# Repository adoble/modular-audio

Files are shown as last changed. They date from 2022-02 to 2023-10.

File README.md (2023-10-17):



# Modular Audio Project - Amplifier Module

An class D amplifier module that can select other digital sources (I2S, S/PDIF).

## System Diagram

### Functional Components

<!-- Removed the ELK renderer as causing problems - see https://github.com/mermaid-js/mermaid-cli/issues/594 -->
<!-- Old code was (first line of the mermaid description): -->
<!-- %%{init: {"flowchart": {"defaultRenderer": "elk"}} }%% -->

```mermaid
flowchart LR

main_ctrl["Main Controller"] -- Parallel Bus --- i2sm[I2S-Multiplexer];
wifi --- antenna1((Antenna <br> 1));

main_ctrl -- I2C --- dsp;
main_ctrl -- SPI+2 --- wifi["WiFi Co-Processor"]
i2sm -- I2S --- dsp["Digital Signal <br> Processor"] -- I2S --- amp[Amplifier];
dsp -- I2S --- toslink_out_converter[TOSLINK<br>Converter] -- "S/PDIF" --- toslink_out{{TOSLINK <br> Out}};

style dsp stroke-dasharray: 5 5;
style toslink_out_converter stroke-dasharray: 5 5;
style toslink_out stroke-dasharray: 5 5;

subgraph sources [Sources-In]
    cd{{CD}};
    dvd{{DVD}};
    tos_link_in{{Toslink In}}
end

subgraph source_sel_display [Source Selection Lights]
    direction LR
    cd_source_selected((CD ))
    dvd_source_selected((DVD))
    bluetooth_source_selected((BT ))
    wlan_source_selected((WLAN))
    dab_source_selected((DAB))
end

antenna2((Antenna <br> 2)) --- airlink;
airlink["Airlink/Bluetooth"] -- I2S --- i2sm
cd -- I2S  --- i2sm;
dvd -- "S/PDIF" --- spdif["S/PDIF Module"] -- I2S --- i2sm;
internet-radio["Internet Radio"] -- I2S --- i2sm

tos_link_in -- "S/PDIF" --- toslink_converter[TOSLINK<br>Converter] -- I2S --- i2sm; 
dab["DAB Radio"] -- I2S --- i2sm

amp --- left{{Left}} --- left_spk((Left <br> Speaker)) 
amp --- right{{Right}} --- right_spk((Right <br> Speaker)) 

dsp -- I2S --- sw-dac[Sub-Woofer DAC] --- sw-line-out{{Sub-Woofer<br>Line-Out}} --- active-sw((Active<br>Sub-Woofer))

vol_proc[Volume <br> Processor];
sel_source[Select <br> Source <br>];

subgraph controls[Controls]
    direction TB
    sel_source_btn((Select <br> Source Button))
    vol_knob((Volume <br> Knob))
end

sel_source --- source_sel_display
vol_knob --- vol_proc -- I2C+1--- main_ctrl;
sel_source_btn --- sel_source -- I2C+1--- main_ctrl;

%%click main_ctrl "https://github.com/adoble/modular-audio/blob/main/README.md#controller"%%
%%click i2sm "https://github.com/adoble/modular-audio/tree/main/hardware/i2s-multiplexer" "Click to see sub-repository"%%
```

### Power

```mermaid
    graph LR;

    net{{240V AV}};
    net ---- Relay;
    Relay --- smps[Switched Mode <br> Power Supply];
    smps ---- pwr_24v{24V};
    smps --- reg_5v[5V Regulator];
    smps --- reg_3v3[3.3V Regulator];
    reg_5v --- pwr_5v{5V};
    reg_3v3 --- pwr_3v3{3.3V};

    Battery --- pwr_on_off(("Power <br> On/Off <br> Switch")) --- Relay; 
```

### Symbols used in the Diagrams

```mermaid
graph LR;

subgraph key[Key]
    transducer((<small>Transducer<small>)) ---  pwr_net{<small>Power<br>Net<small>} --- module[<small>Hardware Module<small>] --- ext{{<small>External<br>Connection<small>}};
end
style key stroke-dasharray: 5 5, fill-opacity: 0;

%% Render links invisible
linkStyle 0 stroke:none
linkStyle 1 stroke:none
linkStyle 2 stroke:none
```

<!-- ![System Diagram](./docs/img/Modular-Amplifier.png) -->

## Functional Component Descriptions

### Controller

Work in Progress!

The controller has the following tasks:

* Select sources
* Receive input fron the volume control and adjust the volume over the DSP. 
* Receive input from the button banks. These are used to interact with the display. 
* Interface with an (Airlift) Wifi board over an extended SPI interface. This is used to download station lists and also 
to control the internet radio module.

Software is [here](/software/main-controller).

Hardware is [here](/hardware/controller).

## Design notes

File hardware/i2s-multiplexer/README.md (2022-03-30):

# I2S Multiplexer

This module routes I2S signals up to 6 sources to the amplifier module  - see the [module overview](../../README.md).

The design principles are:

* Each I2S signal (BCLK, LRCLK, DATA, MCLK) belonging to source are routed through the same buffers so has to minimise differences in buffer propagation delays and with it, differences in the relative timing of the signals with one another. 
* Each I2S signal belonging to a source have the the same track length - gain to moinimisd differences in the relative timing of the signals with one another. 

## Control Signals 

| Signal | Description |
| --- | --- |
| A0, A1, A2 | Address of the source required. Only addresses from 0x0 to 0x5 are allowed. If another address is given the behaviour is not defined. |
| SRC_EN | This should be set LOW before changing  A0..2 and HIGH again once they have been set. | 

## Power

The board requires 3.3 Volt.

## Schematic

Schematic done with [KiCad 6](https://www.kicad.org/) and all files are in this format. An image of the schmematic is:

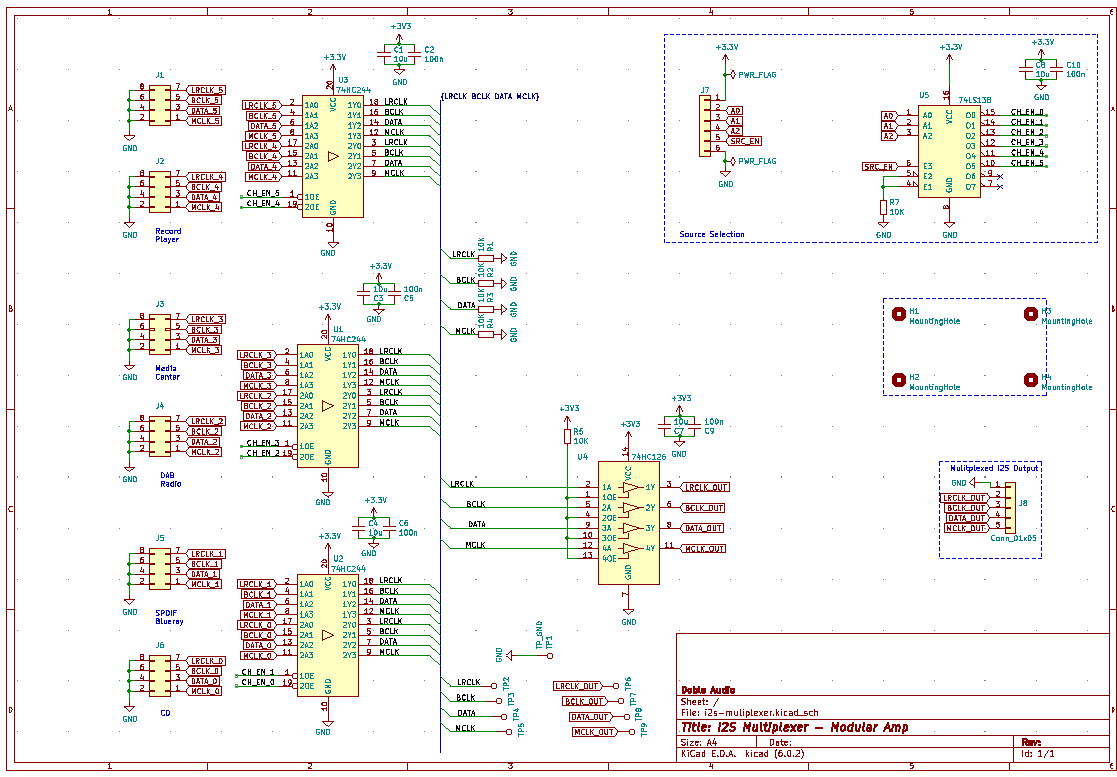
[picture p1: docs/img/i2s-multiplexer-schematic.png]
Schematic


## PCB Layout 

PCB layout is done with [KiCad 6](https://www.kicad.org/)and all files are in this format. An image of the PCB layout is:

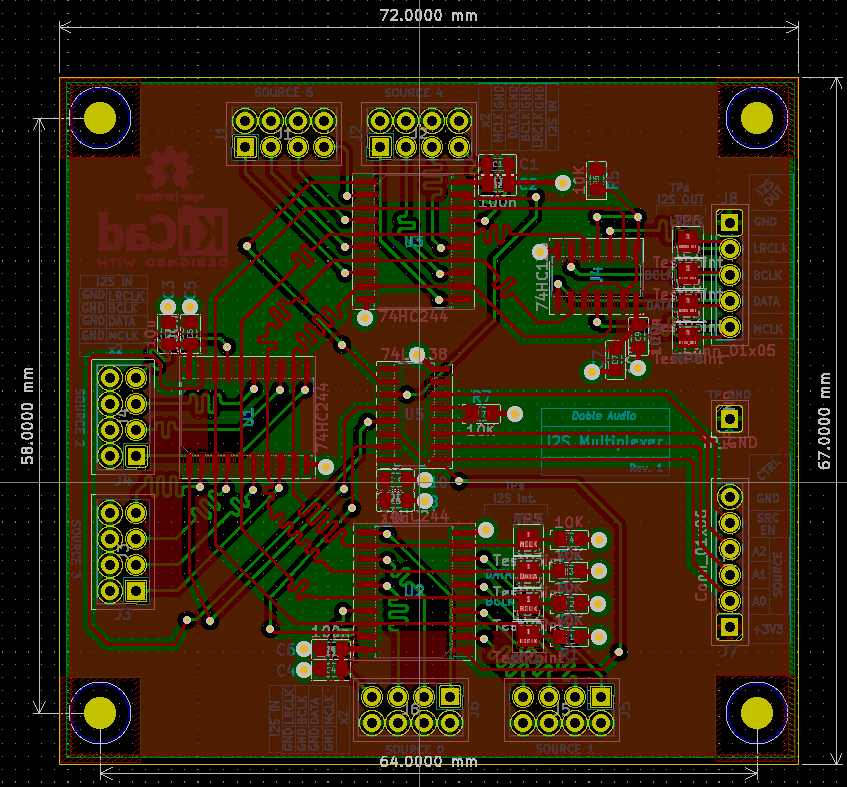
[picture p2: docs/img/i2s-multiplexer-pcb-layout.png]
PCB Layout


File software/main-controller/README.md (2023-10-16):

This is the main controller software for the modular amplifier.

It uses the [Embassy](https://embassy.dev/) framework for running asynchronous tasks. 

# Project Structure

TODO

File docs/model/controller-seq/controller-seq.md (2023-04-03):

# Controller Sequence Diagram

```mermaid

sequenceDiagram

participant system
participant [task]init
participant [task]select_source
participant [struct]SelectSourceDriver
participant [struct]Source
participant [struct]I2SMultiplexerDriver

system--) [task]init : start
activate [task]init
[task]init->>+SelectSourceDriver: new
SelectSourceDriver->>-[task]init: select_source_driver
deactivate [task]init

system--)[task]select_source :  interrupt on source change
activate [task]select_source
[task]select_source->>+SelectSourceDriver : changed_source

SelectSourceDriver->>-[task]select_source : source
[task]select_source->>[struct]Source : activate

[struct]Source->>[struct]I2SMultiplexerDriver : set_source

deactivate [task]select_source

```

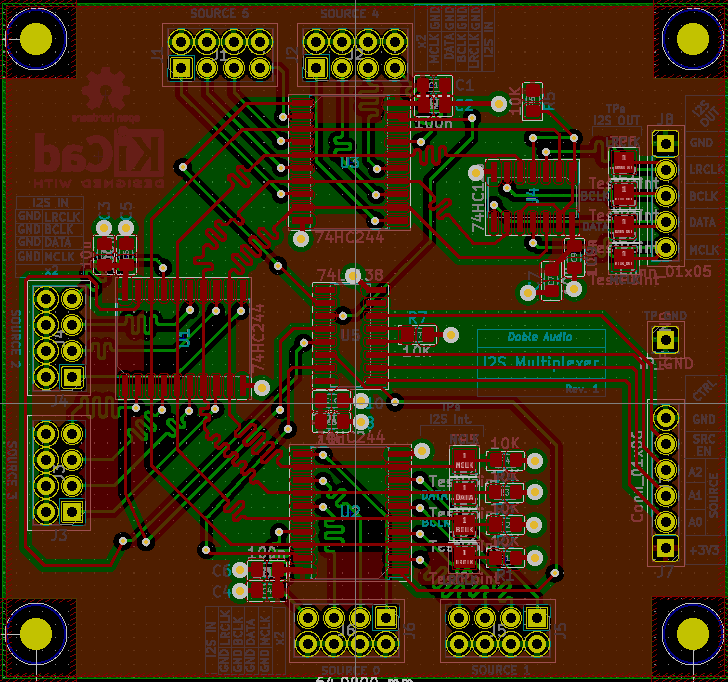
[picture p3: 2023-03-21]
docs/img/i2s-multiplexer-pcb-layout.bmp

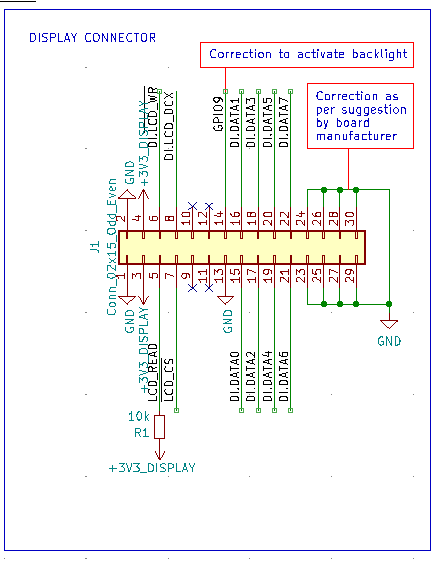
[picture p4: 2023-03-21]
docs/img/controller-display-connector.png

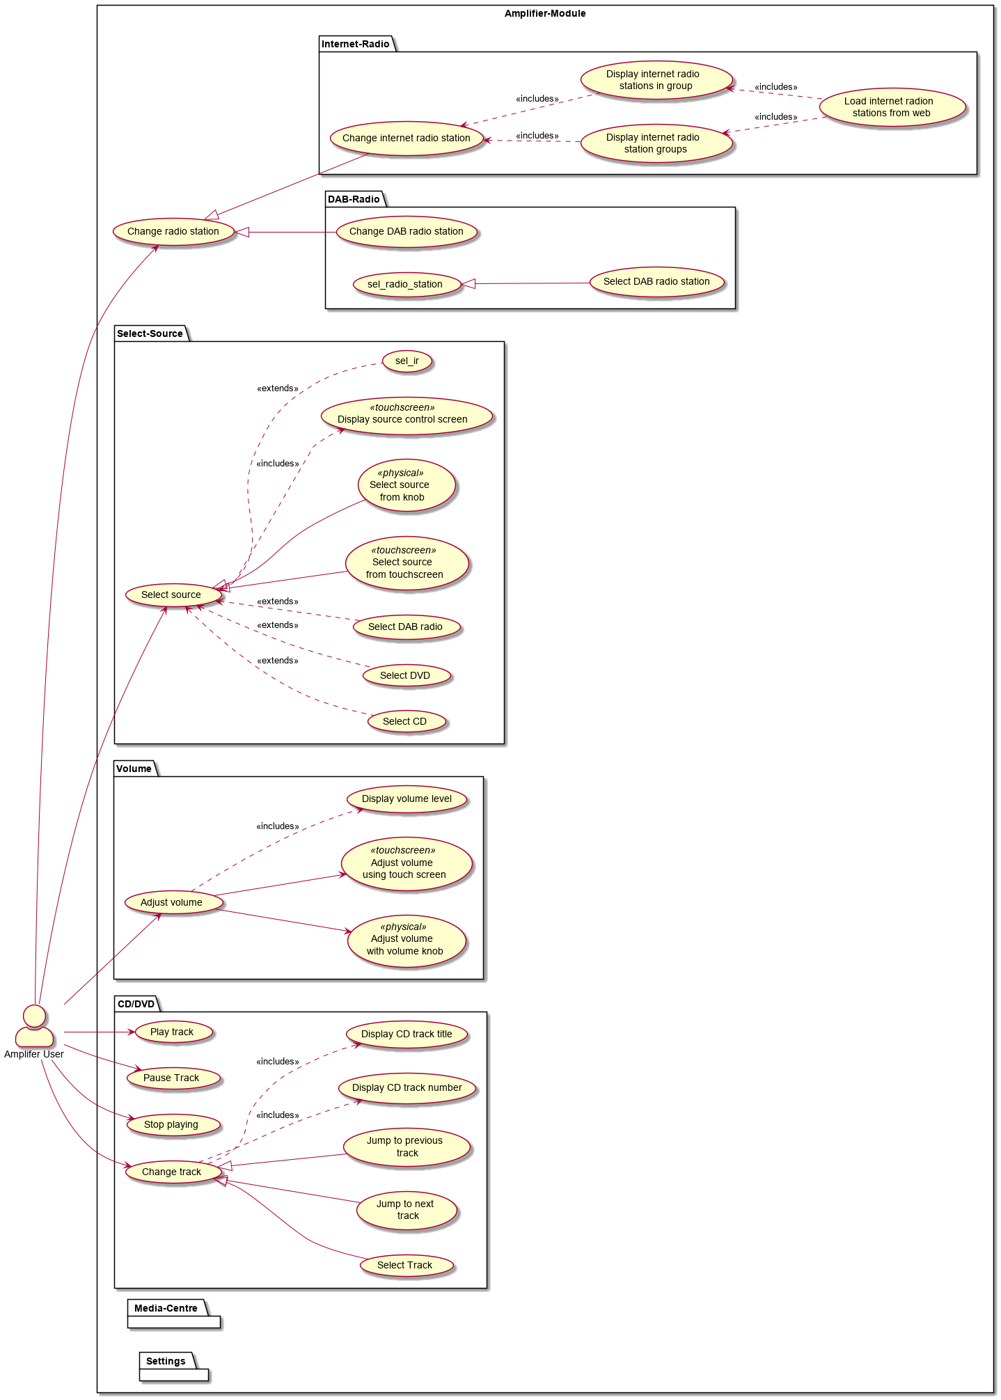
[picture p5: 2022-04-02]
out/docs/model/use-cases/use-cases/use-cases-page1.png

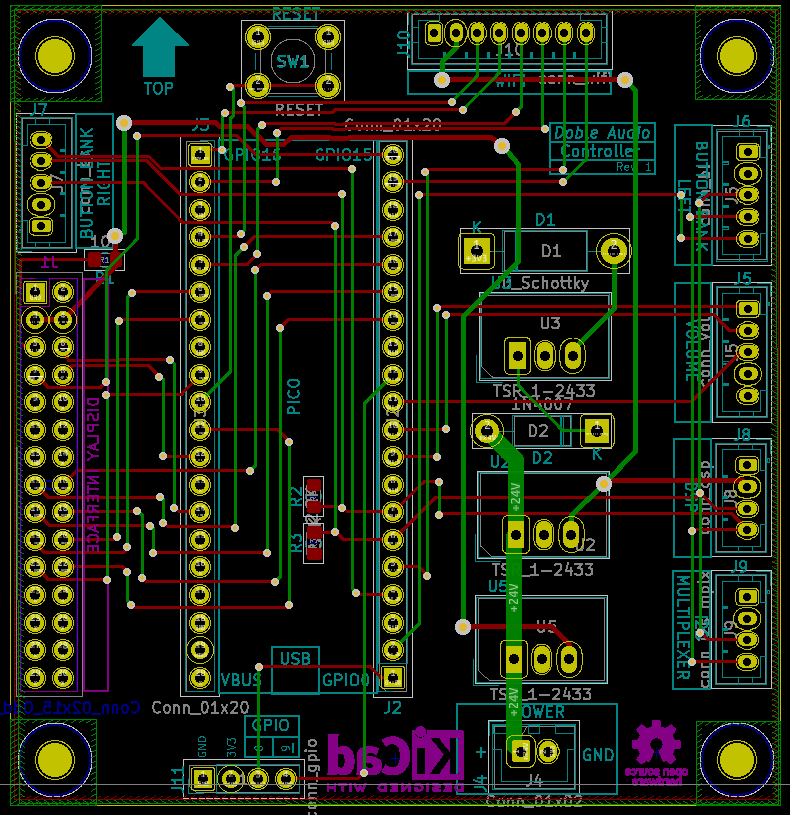
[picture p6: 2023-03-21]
docs/img/controller-pcb.png

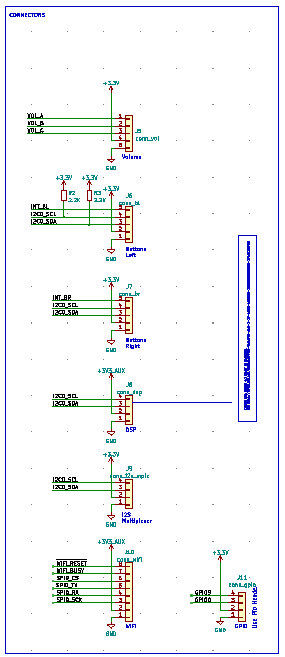
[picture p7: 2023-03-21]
docs/img/controller-connectors.png

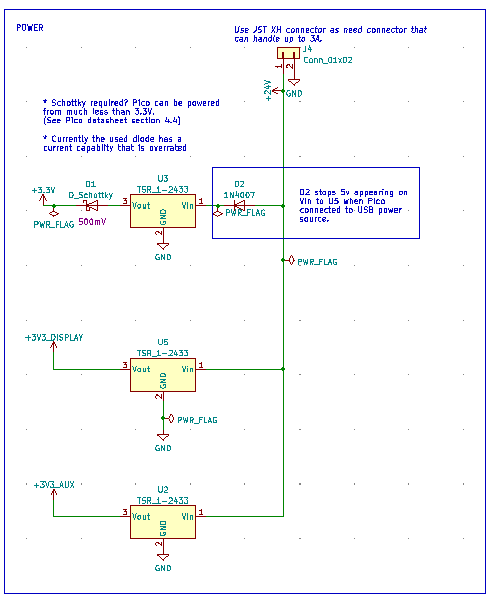
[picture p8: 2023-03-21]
docs/img/controller-power.png

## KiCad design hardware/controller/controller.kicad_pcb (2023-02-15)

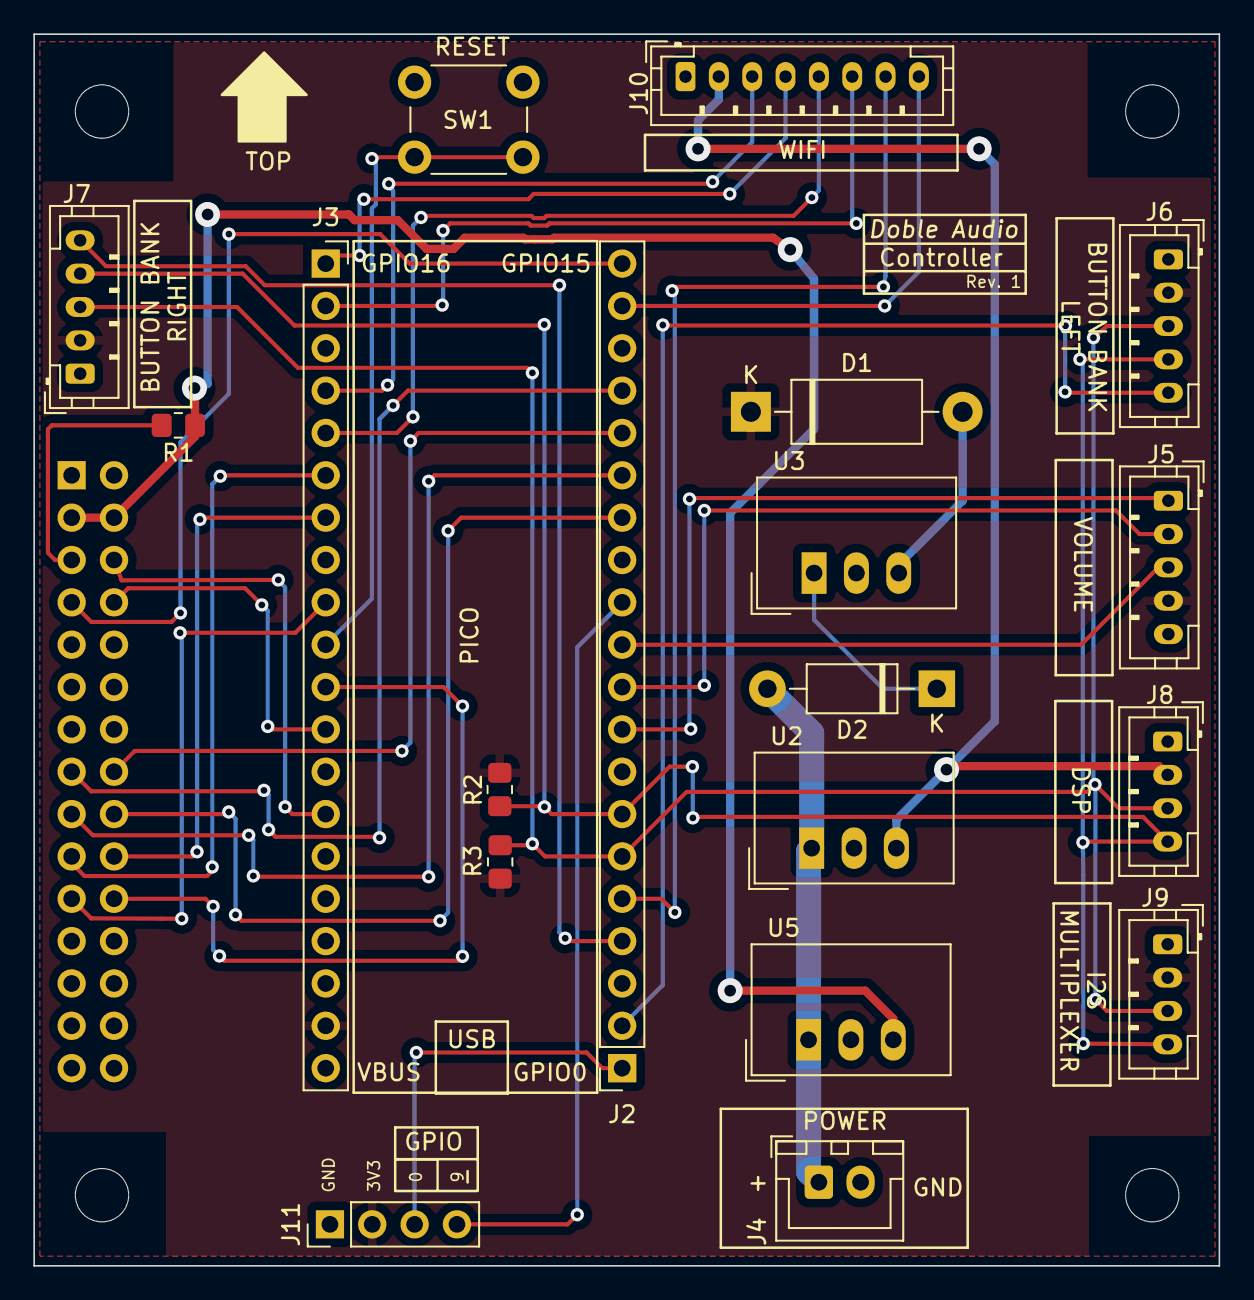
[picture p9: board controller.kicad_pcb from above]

Board: 2 copper layers, 71.1 x 73.9 mm, 24 parts (1 on the bottom side), 35 nets.

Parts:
D1: D_Schottky; D_DO-15_P12.70mm_Horizontal
D2: 1N4007; D_DO-41_SOD81_P10.16mm_Horizontal
H1, H2, H3, H4: MountingHole; MountingHole_3.2mm_M3
J1: Conn_02x15_Odd_Even; PinSocket_2x15_P2.54mm_Vertical
J2, J3: Conn_01x20; PinSocket_1x20_P2.54mm_Vertical
J4: Conn_01x02; JST_XH_B2B-XH-A_1x02_P2.50mm_Vertical
J5: conn_vol; JST_PH_B5B-PH-K_1x05_P2.00mm_Vertical
J6: conn_bl; JST_PH_B5B-PH-K_1x05_P2.00mm_Vertical
J7: conn_br; JST_PH_B5B-PH-K_1x05_P2.00mm_Vertical
J8: conn_dsp; JST_PH_B4B-PH-K_1x04_P2.00mm_Vertical
J9: conn_i2s_mplx; JST_PH_B4B-PH-K_1x04_P2.00mm_Vertical
J10: conn_wifi; JST_PH_B8B-PH-K_1x08_P2.00mm_Vertical
J11: conn_gpio; PinHeader_1x04_P2.54mm_Vertical
R1: 10k; R_0805_2012Metric_Pad1.20x1.40mm_HandSolder
R2, R3: 2.2K; R_0805_2012Metric_Pad1.20x1.40mm_HandSolder
SW1: RESET; SW_PUSH_6mm_H4.3mm
U2, U3, U5: TSR_1-2433; Converter_DCDC_TRACO_TSR-1_THT

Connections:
+3V3: D1.1 (K), J3.19, J5.4, J6.2, J7.2, J9.2, J11.2, R2.1, R3.1
+3V3_AUX: J8.2, J10.2, U2.3 (Vout)
+3V3_DISPLAY: J1.3, J1.4, R1.1, U5.3 (Vout)
+24V: D2.2 (A), J4.1, U2.1 (Vin), U5.1 (Vin)
/DI.DATA0: J1.15, J2.17
/DI.DATA1: J1.16, J2.16
/DI.DATA2: J1.17, J2.15
/DI.DATA3: J1.18, J2.14
/DI.DATA4: J1.19, J3.6
/DI.DATA5: J1.20, J3.7
/DI.DATA6: J1.21, J3.9
/DI.DATA7: J1.22, J3.11
/DI.LCD_DCX: J1.8, J3.12
/DI.~LCD_WR: J1.6, J3.14
/GPIO0: J2.1, J11.3
/GPIO9: J2.12, J11.4
/I2C0_SCL: J2.7, J6.4, J7.4, J8.4, J9.4, R2.2
/I2C0_SDA: J2.6, J6.3, J7.3, J8.3, J9.3, R3.2
/INT_BL: J2.2, J6.5
/INT_BR: J2.4, J7.5
/LCD_READ: J1.5, R1.2
/MCU_RESET: J3.10, SW1.2
/SPI0_CS: J3.2, J10.6
/SPI0_RX: J3.1, J10.4
/SPI0_SCK: J3.4, J10.3
/SPI0_TX: J3.5, J10.5
/VOL_A: J2.9, J5.1
/VOL_B: J2.10, J5.2
/VOL_C: J2.11, J5.3
/WIFI_BUSY: J2.5, J10.7
/~LCD_CS: J1.7, J2.20
/~WIFI_RESET: J2.19, J10.8
GND: J1.1, J1.2, J1.13, J2.3, J2.8, J2.13, J2.18, J3.3, J3.8, J3.18, J4.2, J5.5, J6.1, J7.1, J8.1, J9.1, J10.1, J11.1, SW1.1, U2.2 (GND), U3.2 (GND), U5.2 (GND)
unnamed: D1.2 (A), U3.3 (Vout)
unnamed: D2.1 (K), U3.1 (Vin)

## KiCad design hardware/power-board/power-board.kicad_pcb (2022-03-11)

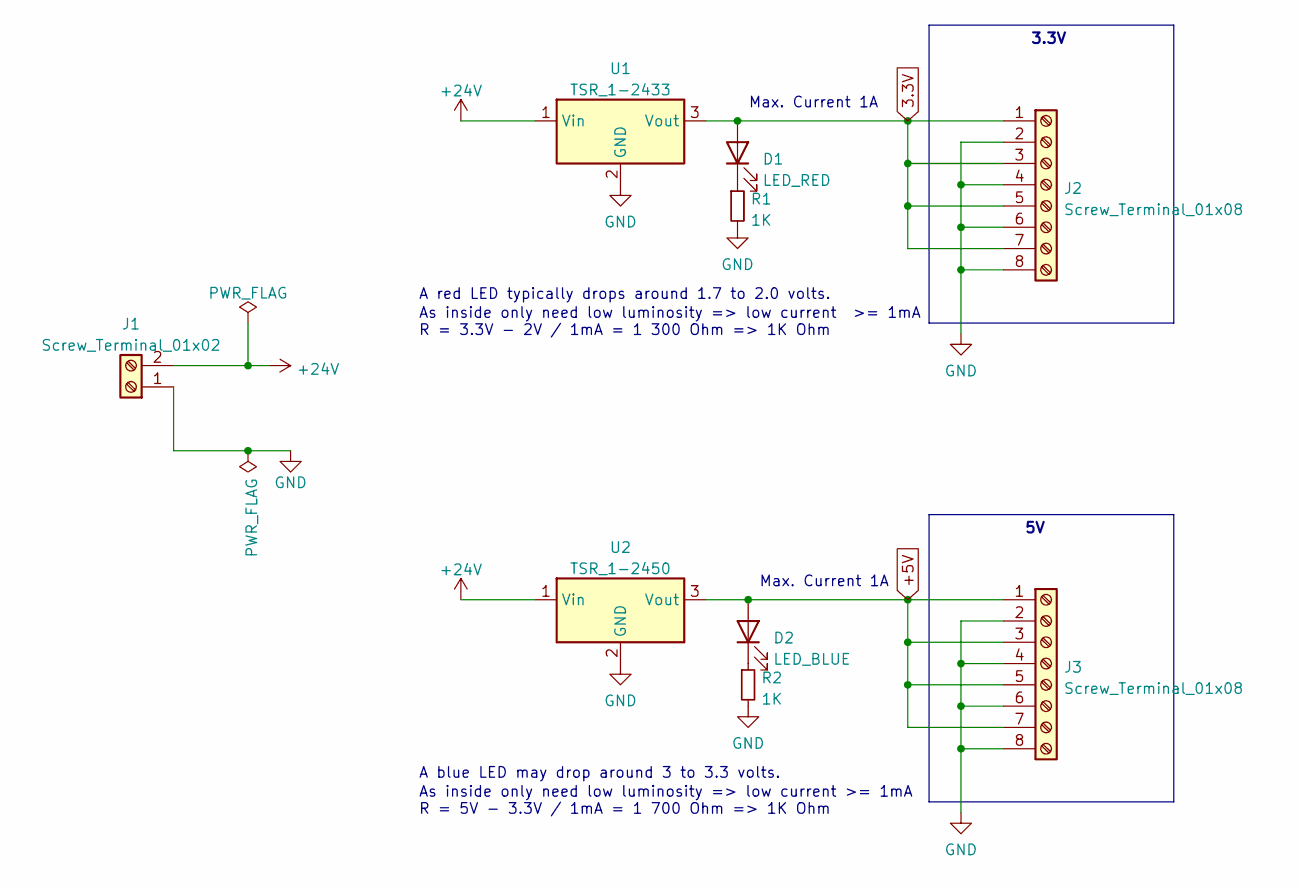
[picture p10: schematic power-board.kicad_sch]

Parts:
D1: LED_RED; LED_0805_2012Metric_Pad1.15x1.40mm_HandSolder
D2: LED_BLUE; LED_0805_2012Metric_Pad1.15x1.40mm_HandSolder
J1: Screw_Terminal_01x02; TerminalBlock_bornier-2_P5.08mm
J2, J3: Screw_Terminal_01x08; TerminalBlock_Phoenix_MKDS-3-8-5.08_1x08_P5.08mm_Horizontal
R1, R2: 1K; R_0805_2012Metric_Pad1.20x1.40mm_HandSolder
U1: TSR_1-2433; Converter_DCDC_TRACO_TSR-1_THT
U2: TSR_1-2450; Converter_DCDC_TRACO_TSR-1_THT

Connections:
3.3V: D1.2 (A), J2.1, J2.3, J2.5, J2.7, U1.3 (Vout)
+5V: D2.2 (A), J3.1, J3.3, J3.5, J3.7, U2.3 (Vout)
+24V: J1.2, U1.1 (Vin), U2.1 (Vin)
GND: J1.1, J2.2, J2.4, J2.6, J2.8, J3.2, J3.4, J3.6, J3.8, R1.2, R2.2, U1.2 (GND), U2.2 (GND)
unnamed: D1.1 (K), R1.1
unnamed: D2.1 (K), R2.1

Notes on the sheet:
Max. Current 1A
As inside only need low luminosity => low current >= 1mA R = 3.3V - 2V / 1mA = 1 300 Ohm => 1K Ohm
A red LED typically drops around 1.7 to 2.0 volts.
3.3V
As inside only need low luminosity => low current >= 1mA R = 5V - 3.3V / 1mA = 1 700 Ohm => 1K Ohm
A blue LED may drop around 3 to 3.3 volts.

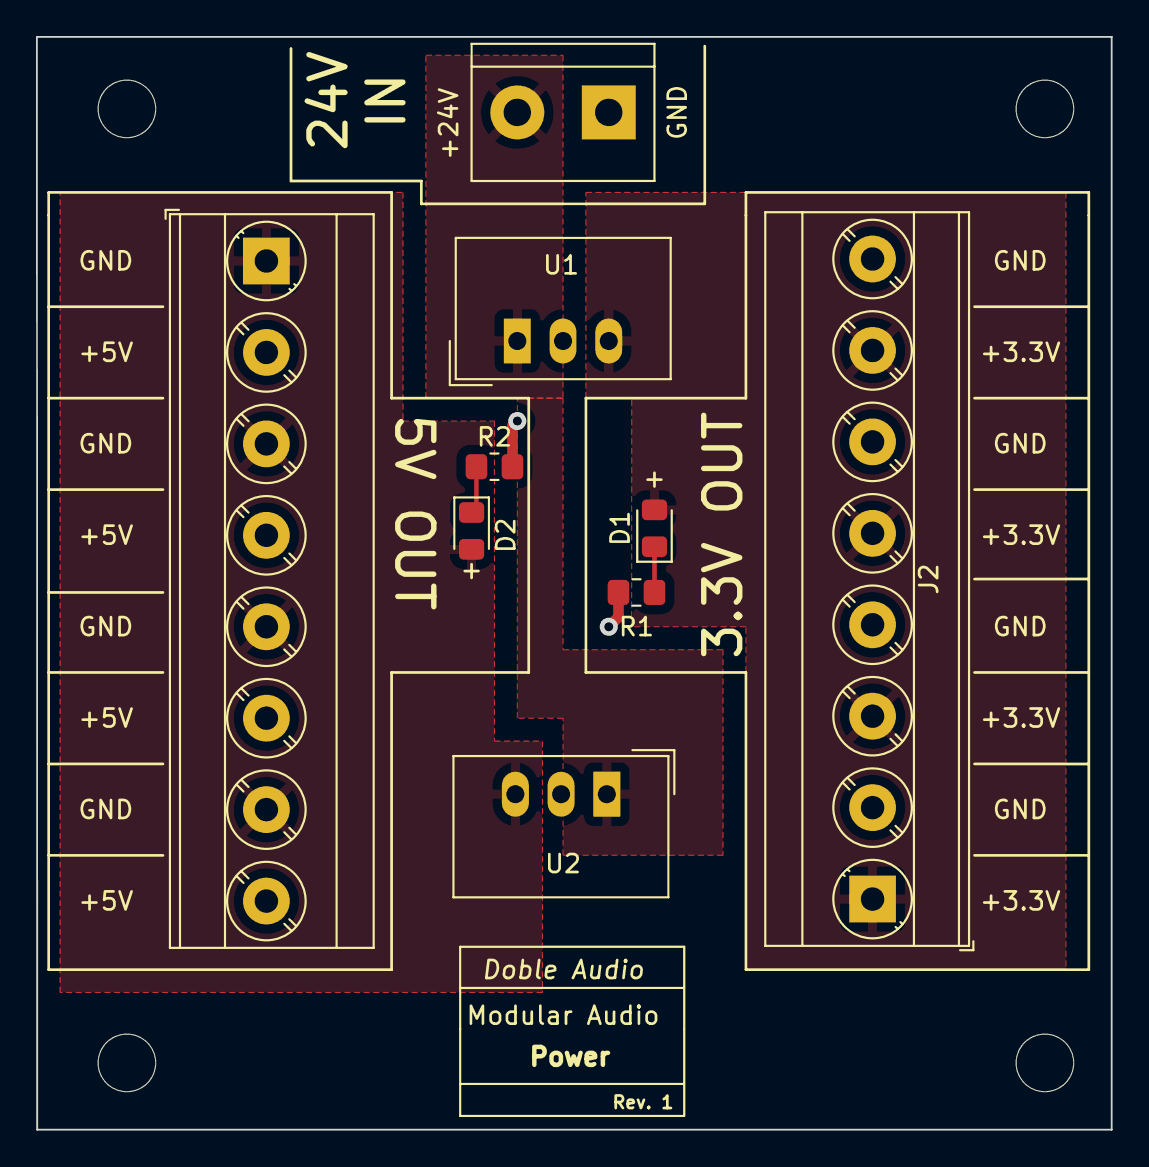
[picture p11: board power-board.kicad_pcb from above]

Board: 2 copper layers, 59.7 x 60.7 mm, 9 parts (0 on the bottom side), 6 nets.

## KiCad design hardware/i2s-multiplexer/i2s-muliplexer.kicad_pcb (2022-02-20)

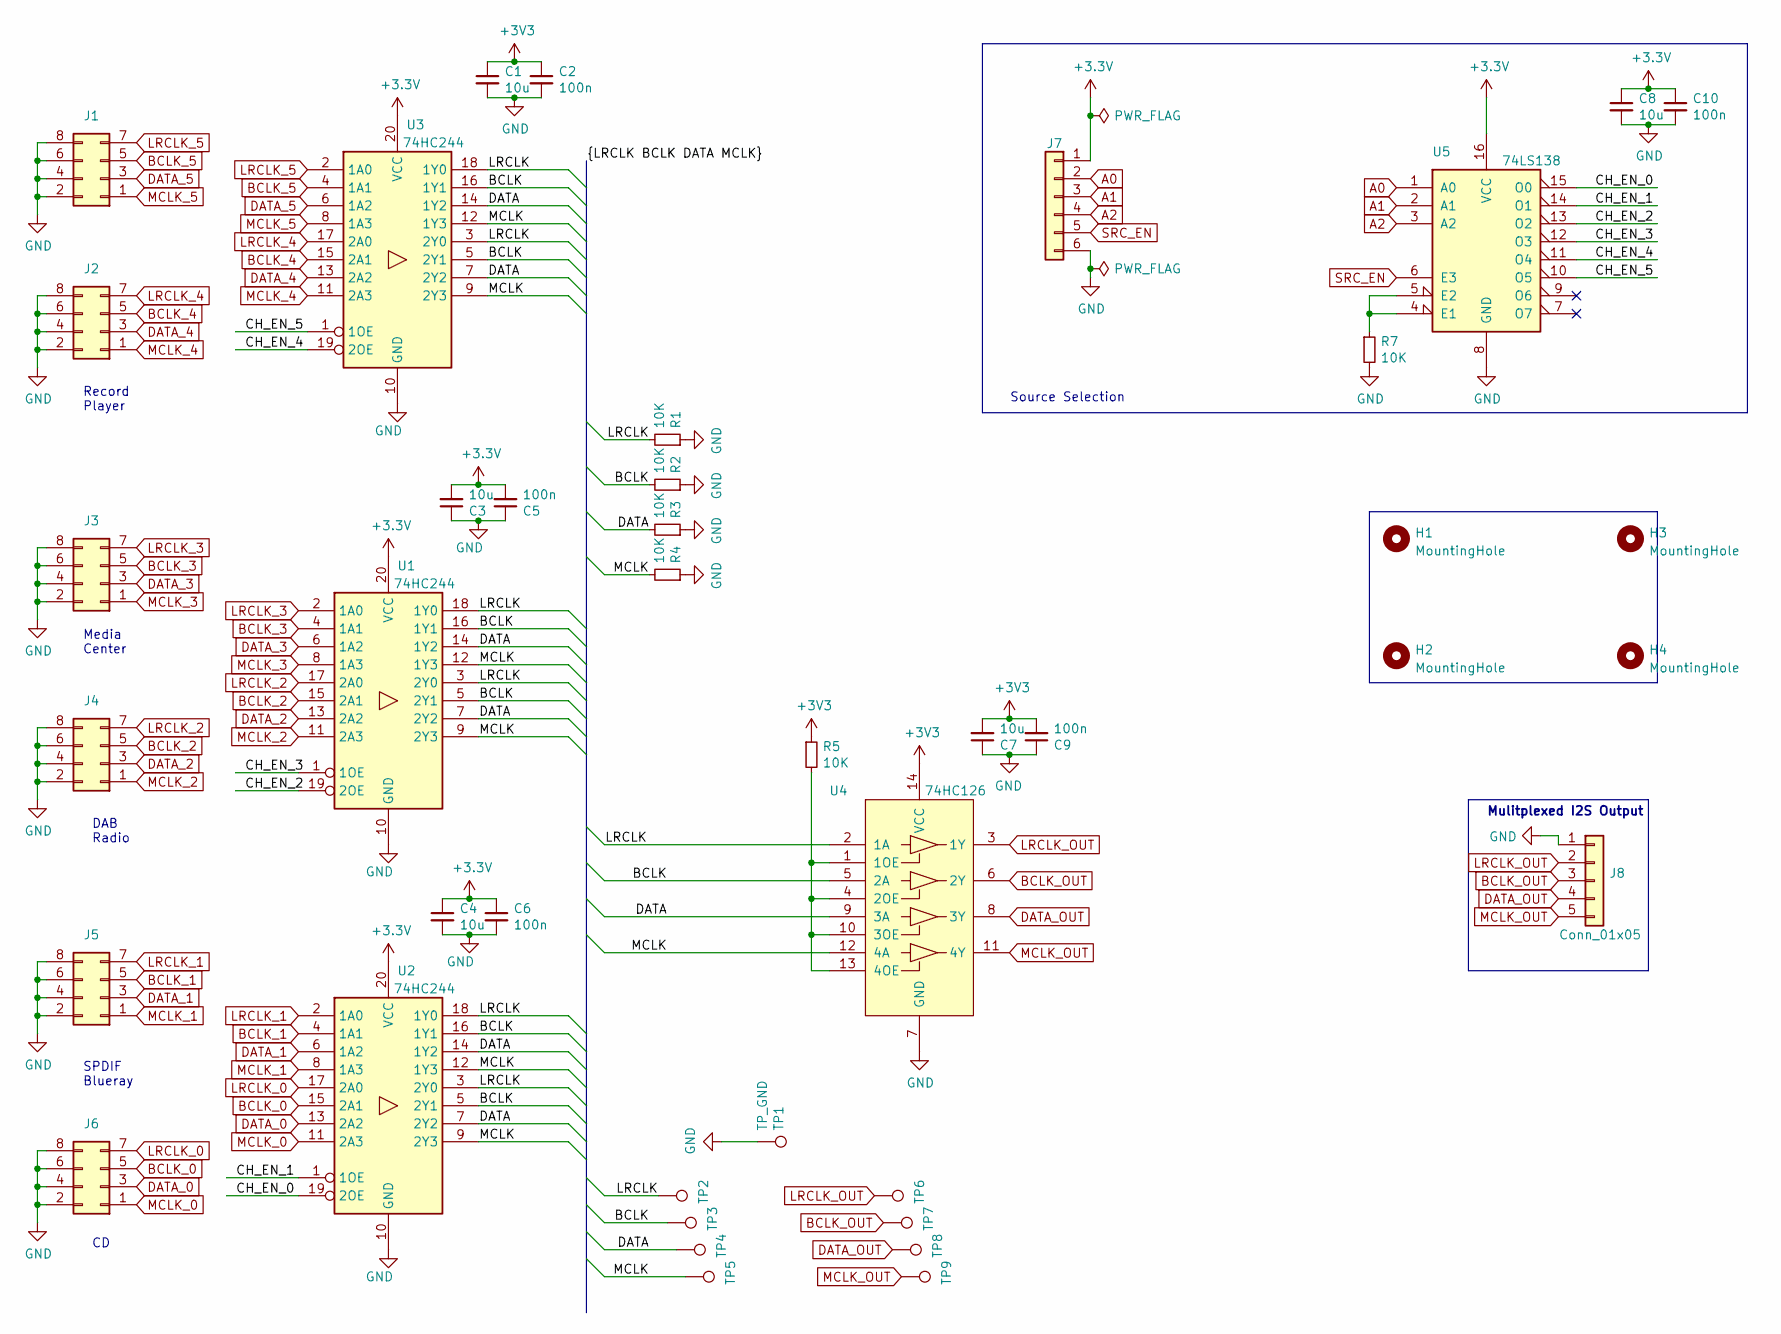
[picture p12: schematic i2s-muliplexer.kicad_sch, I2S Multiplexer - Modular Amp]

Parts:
C1, C3, C4, C7, C8: 10u; C_0805_2012Metric_Pad1.15x1.40mm_HandSolder
C2, C5, C6, C9, C10: 100n; C_0805_2012Metric_Pad1.15x1.40mm_HandSolder
H1, H2, H3, H4: MountingHole; MountingHole_3.2mm_M3_DIN965
J1, J2, J3, J4, J5, J6: Conn_02x04_Odd_Even; PinHeader_2x04_P2.54mm_Vertical
J7: Conn_01x06; PinHeader_1x06_P2.54mm_Vertical
J8: Conn_01x05; PinHeader_1x05_P2.54mm_Vertical
R1, R2, R3, R4, R5, R7: 10K; R_0805_2012Metric_Pad1.15x1.40mm_HandSolder
TP1: TP_GND; PinHeader_1x01_P2.54mm_Vertical
TP2, TP3, TP4, TP5, TP6, TP7, TP8, TP9: TestPoint; TestPoint_Pad_2.0x2.0mm
U1, U2, U3: 74HC244; SOIC-20W_7.5x12.8mm_P1.27mm
U4: 74HC126; SOIC-14_3.9x8.7mm_P1.27mm
U5: 74LS138; SOIC-16_3.9x9.9mm_P1.27mm

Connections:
/BCLK: R2.2, TP3.1, U1.5 (2Y1), U1.16 (1Y1), U2.5 (2Y1), U2.16 (1Y1), U3.5 (2Y1), U3.16 (1Y1), U4.5 (2A)
/CH_EN_0: U2.19 (2OE), U5.15 (O0)
/CH_EN_1: U2.1 (1OE), U5.14 (O1)
/CH_EN_2: U1.19 (2OE), U5.13 (O2)
/CH_EN_3: U1.1 (1OE), U5.12 (O3)
/CH_EN_4: U3.19 (2OE), U5.11 (O4)
/CH_EN_5: U3.1 (1OE), U5.10 (O5)
/DATA: R3.2, TP4.1, U1.7 (2Y2), U1.14 (1Y2), U2.7 (2Y2), U2.14 (1Y2), U3.7 (2Y2), U3.14 (1Y2), U4.9 (3A)
/LRCLK: R1.2, TP2.1, U1.3 (2Y0), U1.18 (1Y0), U2.3 (2Y0), U2.18 (1Y0), U3.3 (2Y0), U3.18 (1Y0), U4.2 (1A)
/MCLK: R4.2, TP5.1, U1.9 (2Y3), U1.12 (1Y3), U2.9 (2Y3), U2.12 (1Y3), U3.9 (2Y3), U3.12 (1Y3), U4.12 (4A)
A0: J7.2, U5.1 (A0)
A1: J7.3, U5.2 (A1)
A2: J7.4, U5.3 (A2)
BCLK_0: J6.5, U2.15 (2A1)
BCLK_1: J5.5, U2.4 (1A1)
BCLK_2: J4.5, U1.15 (2A1)
BCLK_3: J3.5, U1.4 (1A1)
BCLK_4: J2.5, U3.15 (2A1)
BCLK_5: J1.5, U3.4 (1A1)
BCLK_OUT: J8.3, TP7.1, U4.6 (2Y)
DATA_0: J6.3, U2.13 (2A2)
DATA_1: J5.3, U2.6 (1A2)
DATA_2: J4.3, U1.13 (2A2)
DATA_3: J3.3, U1.6 (1A2)
DATA_4: J2.3, U3.13 (2A2)
DATA_5: J1.3, U3.6 (1A2)
DATA_OUT: J8.4, TP8.1, U4.8 (3Y)
GND: C1.2, C2.2, C3.1, C4.2, C5.1, C6.2, C7.1, C8.2, C9.1, C10.2, J1.2, J1.4, J1.6, J1.8, J2.2, J2.4, J2.6, J2.8, J3.2, J3.4, J3.6, J3.8, J4.2, J4.4, J4.6, J4.8, J5.2, J5.4, J5.6, J5.8, J6.2, J6.4, J6.6, J6.8, J7.6, J8.1, R1.1, R2.1, R3.1, R4.1, R7.2, TP1.1, U1.10 (GND), U2.10 (GND), U3.10 (GND), U4.7 (GND), U5.8 (GND); also elsewhere on the board
LRCLK_0: J6.7, U2.17 (2A0)
LRCLK_1: J5.7, U2.2 (1A0)
LRCLK_2: J4.7, U1.17 (2A0)
LRCLK_3: J3.7, U1.2 (1A0)
LRCLK_4: J2.7, U3.17 (2A0)
LRCLK_5: J1.7, U3.2 (1A0)
LRCLK_OUT: J8.2, TP6.1, U4.3 (1Y)
MCLK_0: J6.1, U2.11 (2A3)
MCLK_1: J5.1, U2.8 (1A3)
MCLK_2: J4.1, U1.11 (2A3)
MCLK_3: J3.1, U1.8 (1A3)
MCLK_4: J2.1, U3.11 (2A3)
MCLK_5: J1.1, U3.8 (1A3)
MCLK_OUT: J8.5, TP9.1, U4.11 (4Y)
unnamed: R5.2, U4.1 (1OE), U4.4 (2OE), U4.10 (3OE), U4.13 (4OE)
unnamed: R7.1, U5.4 (E1), U5.5 (E2)
SRC_EN: J7.5, U5.6 (E3)

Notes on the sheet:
Mulitplexed I2S Output
Media Center
Source Selection
SPDIF Blueray
Record Player
DAB Radio

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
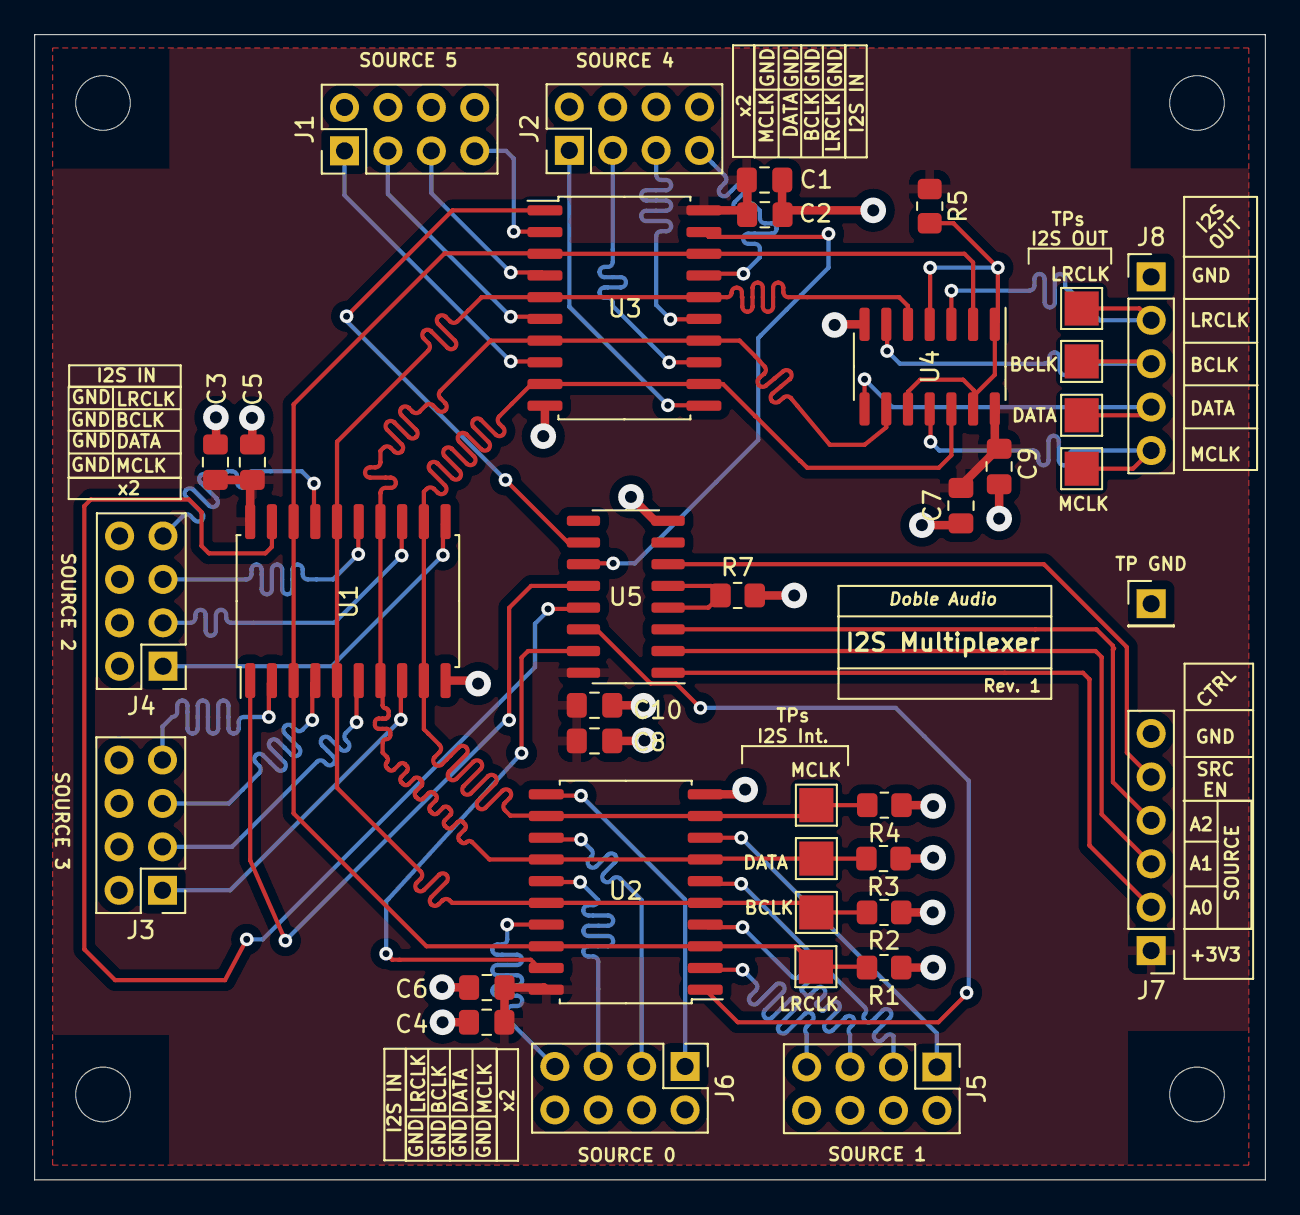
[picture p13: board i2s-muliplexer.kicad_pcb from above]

Board: 2 copper layers, 72.0 x 67.0 mm, 42 parts (0 on the bottom side), 46 nets.

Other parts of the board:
TP GND: TP_GND; PinHeader_1x01_P2.54mm_Vertical

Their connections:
GND: TP GND.1; also elsewhere on the board

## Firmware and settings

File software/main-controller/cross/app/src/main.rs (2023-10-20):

//! Selects a source based on the interruts delivered by the source_select_processor and changes
//! the LEDS on the source_select_processor accordingly.
//!
//! Circuit:
//!     Source select button (pulled up, active low) -> MCP23017::GPB0
//!     MCP23017::GPA[0..5]  -> LEDS for each channel
//!     MCP23017::INTB (change, active low) -> MCU::GPIO1
//!     MCP23017::[SDA, SCL] -> MCU::I2C1[SDA, SCL]
//!     Pulldown Button -> MCU::GPIO1
//!  - Process the interrupt over GPIO 1 (button has been pressed).
//!

// TODOs
// - Maybe need to use shared-bus, see https://docs.rs/shared-bus/latest/shared_bus/ and the referenced blog post.
//
// DEVELOPMENT NOTE:
// - Using https://github.com/lulf/watchful/blob/main/firmware/app/src/main.rs as an example do two things:
//

#![no_std]
#![no_main]
// #![feature(default_alloc_error_handler)] // Stable since 1.68.0 and no longer requires an attribute to enable
#![feature(type_alias_impl_trait)]

// Included modules
mod source_select_driver;

// Imports
use defmt as _;
use defmt_rtt as _;
//#[cfg(feature = "panic-probe")]
use panic_probe as _;

// Required as Sources uses Vec.
extern crate alloc;

use embedded_alloc::Heap;
#[global_allocator]
static HEAP: Heap = Heap::empty();

// Emabssy imports.
use embassy_executor::Spawner;
use embassy_rp::gpio; // gpio::peripherals::PIN_1,
use embassy_rp::peripherals::{PIN_1, PIN_10, PIN_11, PIN_12, PIN_13};
use embassy_time::{Duration, Timer};

use embassy_sync::blocking_mutex::raw::CriticalSectionRawMutex;
use embassy_sync::mutex::Mutex; // Is this the right one? TODO - Using an async mutex

use embassy_rp::i2c::{self, Blocking, Config, I2c};
use embassy_rp::peripherals::I2C0;
use embassy_rp::uart;
use gpio::{Input, Level, Output, Pull};

// Controller specific crates
use crate::source_select_driver::SourceSelectDriver;
use i2s_multiplexer::I2SMultiplexer;
use up2stream_uart::{Source as Up2StreamSource, Up2Stream};

// Data structures used
use channel::Channel;
use sources::{DisplayPosition, Source, SourceConfig, Sources};

// The driver types are omplicated and need to be explictly set for the shared variable.
// To keep this more more manageble a number of types are defined here.

// Pin Types for I2S multiplexer
type MuxAddr0 = Output<'static, PIN_10>;
type MuxAddr1 = Output<'static, PIN_11>;
type MuxAddr2 = Output<'static, PIN_12>;
type MuxEnable = Output<'static, PIN_13>;

// Pin types for UART
//type UartTx = Output<'static, PIN_8>;
//type UartRx = Output<'static, PIN_9>;

// Driver types
type MultiplexerDriver = I2SMultiplexer<MuxAddr0, MuxAddr1, MuxAddr2, MuxEnable>;
type Up2StreamDriver =
    Up2Stream<uart::Uart<'static, embassy_rp::peripherals::UART1, uart::Blocking>>;

// I2C type
type I2CBus = I2c<'static, I2C0, Blocking>;

// Shared resources
// Using the async mutex type as the structures are shared across aynch tasks.
static SHARED_SOURCES: Mutex<CriticalSectionRawMutex, Option<Sources>> = Mutex::new(None);
static SHARED_I2S_MULTIPLEXER: Mutex<CriticalSectionRawMutex, Option<MultiplexerDriver>> =
    Mutex::new(None);
static SHARED_SOURCE_SELECTION_DRIVER: Mutex<
    CriticalSectionRawMutex,
    Option<SourceSelectDriver<I2CBus>>,
> = Mutex::new(None);
static SHARED_UP2STREAM: Mutex<CriticalSectionRawMutex, Option<Up2StreamDriver>> = Mutex::new(None);

// TODO change this into a proper Duration
const DEBOUNCE_DURATION: u64 = 100; // Milliseconds

#[embassy_executor::main]
async fn main(spawner: Spawner) {
    defmt::info!("Starting main task");

    // Initialise the allocator. Required for data structures.
    // Assuming that 2048 bytes is enough
    {
        use core::mem::MaybeUninit;
        const HEAP_SIZE: usize = 2048;
        static mut HEAP_MEM: [MaybeUninit<u8>; HEAP_SIZE] = [MaybeUninit::uninit(); HEAP_SIZE];
        unsafe { HEAP.init(HEAP_MEM.as_ptr() as usize, HEAP_SIZE) }
    }

    let p = embassy_rp::init(Default::default());

    // Setup an interrupt on pin 1 to register a button press
    // This is configured as an input pin so that the value can be read.
    // TODO change the name of this pin as it is not an interrupt!
    let source_change_pin = Input::new(p.PIN_1, Pull::Up);

    // Setup the pins used for i2c
    let sda_pin = p.PIN_4;
    let scl_pin = p.PIN_5;

    // The MCP23017 mulitplexer chip used to driver the source lights can use a 400 KHz clock for I2C.
    // However, embassy (currently) only allows the default to 100 KHz (as seen from code).
    // Initial test show that the  slower value still works.
    let i2c_config = Config::default(); // Defaults to 100_000 Hz (as seen from code). Hoping that a slower value will still work

    // Setup the I2C peripheral
    let i2c = i2c::I2c::new_blocking(p.I2C0, scl_pin, sda_pin, i2c_config);

    // Set up the  UART
    let uart_config = uart::Config::default();
    let uart = uart::Uart::new_blocking(p.UART1, p.PIN_8, p.PIN_9, uart_config);

    // Set up the source select hardware module as a shared resource
    let address_offset: u8 = 0x01;
    let select_source_driver = SourceSelectDriver::new(i2c, address_offset)
        .unwrap_or_else(|_| defmt::panic!("Cannot initialise select source driver"));

    // Lock the driver mutex and update it with initialised driver by inserting (using insert()) into the Option
    let mut driver = SHARED_SOURCE_SELECTION_DRIVER.lock().await;
    let _ = driver.insert(select_source_driver);

    // Set up the I2S multiplexer driver
    let mux_addr0_pin = Output::new(p.PIN_10, Level::Low);
    let mux_addr1_pin = Output::new(p.PIN_11, Level::Low);
    let mux_addr2_pin = Output::new(p.PIN_12, Level::Low);
    let mux_en_pin = Output::new(p.PIN_13, Level::Low);

    let i2s_multiplexer =
        I2SMultiplexer::new(mux_addr0_pin, mux_addr1_pin, mux_addr2_pin, mux_en_pin)
            .unwrap_or_else(|_| defmt::panic!("Cannot initialise i2s-multiplexer driver"));

    // As the I2S Multiplexer driver is used by other tasks, set it up as a shared resource
    let mut driver = SHARED_I2S_MULTIPLEXER.lock().await;
    let _ = driver.insert(i2s_multiplexer);

    // Set up the up2stream driver as a shared resource
    let up2stream_driver = Up2Stream::new(uart);
    let mut driver = SHARED_UP2STREAM.lock().await;
    let _ = driver.insert(up2stream_driver);

    // Set up the source channel mapping
    let source_bluetooth = Source::Bluetooth(SourceConfig {
        channel: Channel(2),
        display_position: DisplayPosition(0),
    });

    let source_wlan = Source::WirelessLan(SourceConfig {
        channel: Channel(2),
        display_position: DisplayPosition(1),
    });

    let source_aux = Source::Aux(SourceConfig {
        channel: Channel(2),
        display_position: DisplayPosition(2),
    });

    let source_cd = Source::Cd(SourceConfig {
        channel: Channel(4),
        display_position: DisplayPosition(3),
    });

    // Note that sources are ordered depending on the display_position
    let sources =
        sources::Sources::from_array(&[source_bluetooth, source_wlan, source_aux, source_cd]);

    // Setup the sources as a shared resource so that thay can be used by the sources iterator over many tasks
    // Code is based on this https://apollolabsblog.hashnode.dev/sharing-data-among-tasks-in-rust-embassy-synchronization-primitives
    let mut shared_sources = SHARED_SOURCES.lock().await;
    // Insert into the option
    let _ = shared_sources.insert(sources);

    // Run a task to set up the intial source
    spawner.spawn(activate_initial_source()).unwrap();

    // Now monitor for source changes triggered by the user pressing the
    //source selection buttons
    spawner.spawn(source_change(source_change_pin)).unwrap();
}

#[embassy_executor::task]
// Altough only called once this needs to be an async function so that we can use the
// await keyword on the locks
// TODO need a more general way to handle source selection
async fn activate_initial_source() {
    defmt::info!("Task activate_initial_source");

    //let mut sources_iterator = SHARED_SOURCES_ITERATOR.lock().await;
    let mut sources = SHARED_SOURCES.lock().await;

    //if let Some(initial_source) = sources_iterator.unwrap().peek() {
    if let Some(initial_source) = sources.as_mut().unwrap().current_source() {
        // Get the new source channel
        let initial_channel = initial_source.channel();
        // Switch the i2s multiplexer to the correct channel
        // Assuming that the mutliplexer driver is initialized
        // Cannot chain the following two statements together due to lifetime issues
        let mut guard = SHARED_I2S_MULTIPLEXER.lock().await;
        let multiplexer = guard.as_mut().unwrap();

        let channel_number: u8 = initial_channel.channel_number();

        defmt::info!("Setting channel {}", channel_number);

        multiplexer
            .set_channel(channel_number)
            .unwrap_or_else(|_| defmt::panic!("Cannot set channel"))
    } else {
        defmt::panic!("No initial channel set");
    }
}

/// Monitor when the source_changed pin is pulsed low from the
/// select source board and then change the source
#[embassy_executor::task]
async fn source_change(mut source_change_pin: Input<'static, PIN_1>) {
    defmt::info!("Task: monitor_source_change");

    loop {
        source_change_pin.wait_for_falling_edge().await;

        // Debounce
        Timer::after(Duration::from_millis(DEBOUNCE_DURATION)).await;

        if source_change_pin.is_low() {
            // Source change pin is still low so change source
            defmt::info!("Task activate_source");

            // Lock all common resources for each source - assuming that they have been initialised. Note: cannot chain the lock await and the
            // get value together due to lifcycle issues.
            let mut guard = SHARED_SOURCE_SELECTION_DRIVER.lock().await;
            let select_source_driver = guard.as_mut().unwrap();

            let mut guard = SHARED_I2S_MULTIPLEXER.lock().await;
            let i2s_multiplexer_driver = guard.as_mut().unwrap();

            let mut guard = SHARED_SOURCES.lock().await;
            let sources = guard.as_mut().unwrap();

            match select_source_driver.change_source(sources) {
                Ok(()) => {
                    let source = sources.current_source().unwrap();
                    match source {
                        Source::Bluetooth(config) => {
                            // Lock and get the up2stream-uart driver
                            let mut guard = SHARED_UP2STREAM.lock().await;
                            let up2stream_driver = guard.as_mut().unwrap();

                            activate_bluetooth(config, i2s_multiplexer_driver, up2stream_driver);
                        }
                        Source::WirelessLan(config) => {
                            let mut guard = SHARED_UP2STREAM.lock().await;
                            let up2stream_driver = guard.as_mut().unwrap();

                            activate_wireless_lan(config, i2s_multiplexer_driver, up2stream_driver);
                        }
                        Source::Aux(config) => {
                            let mut guard = SHARED_UP2STREAM.lock().await;
                            let up2stream_driver = guard.as_mut().unwrap();

                            activate_aux(config, i2s_multiplexer_driver, up2stream_driver)
                        }

                        _ => defmt::error!("Source not implemented!"),
                    }
                }
                Err(_) => defmt::panic!("Unable to determine changed source"),
            }
        }
    }
}

// TODO & IDEA. Each of the activate* functions needs to have as parameters a seperate set of device drivers.
// Maybe  I can unifiy this by having all the external devices in a global static struct "Devices"(which also
// handles the initialization and "taking" of the devices). This is then analog to the HAL Peripharals struct.
// Each activate* function then takes a reference to this global static struct and coudl be played in a trait, e.g:
//   trait Activation {
//     fn activate(config: SourceConfig, devices: &Devices) { ... }
//   }
//
// and each  Source would be a struct using the trait Source
//    trait Source {
//       fn new (config: SourceConfig);
//    }
//    impl Activate for Source {
//       fn activate( ...) {}
//    }
//    struct SourceBluetooth {
//        config: SourceConfig,
//    }
// impl Source for SourceBluetooth {
//     fn new(config: SourceConfig) {...}
// }
// impl Activation for SourceBluetooth {
//     fn activate(&self, ... , devices: &mut Devices) {}
// }
//
// Even without the traits, putting all the devices in a Device struct could simplify things a bit.
// Maybe think about lazy_static! https://crates.io/crates/lazy_static

fn activate_bluetooth(
    config: SourceConfig,
    i2s_multiplexer_driver: &mut MultiplexerDriver,
    up2stream_driver: &mut Up2StreamDriver,
) {
    defmt::info!("Setting source bluetooth");
    // Switch the up2steam board to the correct source
    up2stream_driver
        .select_input_source(Up2StreamSource::Bluetooth)
        .unwrap(); //TODO error handling!

    // Switch the i2s multiplexer to the correct channel
    let channel_number = config.channel.channel_number();
    defmt::info!("Setting channel {}", channel_number);

    i2s_multiplexer_driver
        .set_channel(channel_number)
        .unwrap_or_else(|_| defmt::panic!("Cannot set channel"));
}

fn activate_wireless_lan(
    config: SourceConfig,
    i2s_multiplexer_driver: &mut MultiplexerDriver,
    up2stream_driver: &mut Up2StreamDriver,
) {
    defmt::info!("Setting source wirless_lan");

    up2stream_driver
        .select_input_source(Up2StreamSource::Net)
        .unwrap(); //TODO error handling!

    // Switch the i2s multiplexer to the correct channel
    let channel_number = config.channel.channel_number();
    defmt::info!("Setting channel {}", channel_number);

    i2s_multiplexer_driver
        .set_channel(channel_number)
        .unwrap_or_else(|_| defmt::panic!("Cannot set channel"));
}

fn activate_aux(
    config: SourceConfig,
    i2s_multiplexer_driver: &mut MultiplexerDriver,
    up2stream_driver: &mut Up2StreamDriver,
) {
    defmt::info!("Setting source aux/line-in");

    up2stream_driver
        .select_input_source(Up2StreamSource::LineIn)
        .unwrap(); //TODO error handling!

    // Switch the i2s multiplexer to the correct channel
    let channel_number = config.channel.channel_number();
    defmt::info!("Setting channel {}", channel_number);

    i2s_multiplexer_driver
        .set_channel(channel_number)
        .unwrap_or_else(|_| defmt::panic!("Cannot set channel"));
}

// End of file

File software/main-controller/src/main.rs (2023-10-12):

//! Selects a source based on the interruts delivered by the source_select_processor and changes
//! the LEDS on the source_select_processor accordingly.
//!
//! Circuit:
//!     Source select button (pulled up, active low) -> MCP23017::GPB0
//!     MCP23017::GPA[0..5]  -> LEDS for each channel
//!     MCP23017::INTB (change, active low) -> MCU::GPIO1
//!     MCP23017::[SDA, SCL] -> MCU::I2C1[SDA, SCL]
//!  - Process the interrupt over GPIO 1 (button has been pressed).  MCP23017 Pin used for the button is GPB0.
//!

// TODOs
// - The mcp23017 is not correctly initialised and can hang in that the "interrupt" stays stuck low.
// - Using https://github.com/lulf/watchful/blob/main/firmware/app/src/main.rs as an example do two things:
//        - Use StaticCell
//        - Only put I2C driver in as mutex. Other drivers, pass in as references to the corresponding functions.
//          However, my first approach would be to continue as is (mutexes on all the drivers) and then see if we can simplify
// - Maybe need to use shared-bus, see https://docs.rs/shared-bus/latest/shared_bus/ and the referenced blog post.
// - Restructure so that we can use std unit tests.
//       See https://ferrous-systems.com/blog/test-embedded-app/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

#![no_std]
#![no_main]
// #![feature(default_alloc_error_handler)] // Stable since 1.68.0 and no longer requires an attribute to enable
#![feature(type_alias_impl_trait)]

//use defmt::*;

// Included modules
//mod channel;
mod error;
mod source_select_driver;
// mod sources;

//use channel::Channel;
//use sources::{Source, SourceIterator, Sources};

// These need to be explicity imported due to the #![cfg_attr(not(test), no_std)] above.
// use core::default::Default;
// use core::marker::Sized;
// use core::module_path;
// use core::option::Option::{self, None, Some};

use defmt as _;
use defmt_rtt as _;
use panic_probe as _;

// use core::cell::RefCell;
// use core::mem::MaybeUninit;

use embassy_executor::Spawner;
use embassy_rp::gpio; // gpio::peripherals::PIN_1,
use embassy_rp::peripherals::{PIN_1, PIN_10, PIN_11, PIN_12, PIN_13};
use embassy_time::{Duration, Timer};

use embassy_sync::blocking_mutex::raw::ThreadModeRawMutex;
use embassy_sync::mutex::Mutex; // Is this the right one? TODO - Using an async mutex

use embassy_rp::i2c::{self, Blocking, Config, I2c};
use embassy_rp::peripherals::I2C0;
use gpio::{Input, Level, Output, Pull};

// Controller specific crates
use crate::source_select_driver::SourceSelectDriver;
use i2s_multiplexer::I2SMultiplexer;

use sources::{DisplayPosition, Source, SourceConfig, SourceIterator, Sources};

use channel::Channel;

// The driver types are omplicated and need to be explictly set for the shared variable.
// To keep this more more manageble a number of types are defined here.
// Pin Types
type MuxAddr0 = Output<'static, PIN_10>;
type MuxAddr1 = Output<'static, PIN_11>;
type MuxAddr2 = Output<'static, PIN_12>;
type MuxEnable = Output<'static, PIN_13>;

// Driver types
type MultiplexerDriver = I2SMultiplexer<MuxAddr0, MuxAddr1, MuxAddr2, MuxEnable>;

// I2C type
type I2CBus = I2c<'static, I2C0, Blocking>;

// Shared resources
// Using the async mutex type as the structures are shared across aynch tasks.
// See https://apollolabsblog.hashnode.dev/sharing-data-among-tasks-in-rust-embassy-synchronization-primitives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
// Is ThreadModeRawMutex the right model? or is NoopRawMutex better as  data is only shared between tasks running on the same executor?
// static SHARED_SOURCES: Mutex<ThreadModeRawMutex, RefCell<Option<Sources>>> =
//     Mutex::new(RefCell::new(None));
static SHARED_SOURCES: Mutex<ThreadModeRawMutex, Option<Sources>> = Mutex::new(None);

// static SHARED_SOURCES_ITERATOR: Mutex<
//     ThreadModeRawMutex,
//     RefCell<Option<SourceIterator<'static>>>,
// > = Mutex::new(RefCell::new(None));
static SHARED_SOURCES_ITERATOR: Mutex<ThreadModeRawMutex, Option<SourceIterator<'static>>> =
    Mutex::new(None);

static SHARED_I2S_MULTIPLEXER: Mutex<ThreadModeRawMutex, Option<MultiplexerDriver>> =
    Mutex::new(None);

static SHARED_SOURCE_SELECTION_DRIVER: Mutex<
    ThreadModeRawMutex,
    Option<SourceSelectDriver<I2CBus>>,
> = Mutex::new(None);

// TODO change this into a proper Duration
const DEBOUNCE_DURATION: u64 = 100; // Milliseconds

#[embassy_executor::main]
async fn main(spawner: Spawner) {
    defmt::info!("Starting main task");

    let p = embassy_rp::init(Default::default());

    // Setup an interrupt on pin 1 to register a button press
    // This is configured as an input pin so that the value can be read.
    // TODO change the name of this pin as it is not an interrupt!
    let source_change_pin = Input::new(p.PIN_1, Pull::Up);

    // Setup the pins used for i2c
    let sda_pin = p.PIN_4;
    let scl_pin = p.PIN_5;
    // let i2c_config = Config {
    //     frequency: 400.khz(),   /// This is what we have been using before
    // };
    let i2c_config = Config::default(); // Defaults to 100_000 Hz (as seen from code). Hoping that a slower value will still work

    // Setup the I2C peripheral
    let i2c = i2c::I2c::new_blocking(p.I2C0, scl_pin, sda_pin, i2c_config);

    // Set up the source select hardware module as a shared resource
    let address_offset: u8 = 0x01;
    let select_source_driver = SourceSelectDriver::new(i2c, address_offset)
        .unwrap_or_else(|_| defmt::panic!("Cannot initialise select source driver"));

    // Lock the driver mutex and update it with initialised driver
    let mut driver = SHARED_SOURCE_SELECTION_DRIVER.lock().await;
    driver.insert(select_source_driver); // inserting into the Option
                                         // SHARED_SOURCE_SELECTION_DRIVER = Mutex::new(Some(select_source_driver));

    // Set up the I2S multiplexer driver
    let mux_addr0_pin = Output::new(p.PIN_10, Level::Low);

    let mux_addr1_pin = Output::new(p.PIN_11, Level::Low);
    let mux_addr2_pin = Output::new(p.PIN_12, Level::Low);
    let mux_en_pin = Output::new(p.PIN_13, Level::Low);

    let i2s_multiplexer =
        I2SMultiplexer::new(mux_addr0_pin, mux_addr1_pin, mux_addr2_pin, mux_en_pin)
            .unwrap_or_else(|_| defmt::panic!("Cannot initialise i2s-multiplexer driver"));

    // As the I2S Multiplexer is used by other tasks, set it up as a shared resource
    //    SHARED_I2S_MULTIPLEXER = Mutex::new(Some(i2s_multiplexer));
    let mut driver = SHARED_I2S_MULTIPLEXER.lock().await;
    driver.insert(i2s_multiplexer);

    // Set up the source channel mapping
    let source_bluetooth = Source::Bluetooth(SourceConfig {
        channel: Channel(2),
        display_position: DisplayPosition(0),
    });

    let source_wlan = Source::WirelessLan(SourceConfig {
        channel: Channel(2),
        display_position: DisplayPosition(1),
    });
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

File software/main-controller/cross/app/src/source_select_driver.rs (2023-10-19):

#![allow(dead_code)]

use embedded_hal as hal;

use hal::blocking::i2c::{Write, WriteRead};

extern crate alloc;

// The driver for the MCP23017 chip used on the board
use mcp23017::MCP23017;

use defmt as _;
use panic_probe as _;

use sources::Sources;

// Defines errors being issued by the MCP23017 chip on the source select board
#[derive(Debug, Copy, Clone)]
pub enum MCP23017Errors {
    // TODO can we use the errors from the mcp23017 driver itself?
    Initialization,
    PinModeInput(u8),
    PinModeOutput(u8),
    InterruptPin,
    DigitalRead(u8), // Contains the pin number
}
/// Defines errors for the driver
#[derive(Debug, Copy, Clone)]
pub enum Error {
    MCP23017(MCP23017Errors),
    ClearLED(u8),
    SetLED,
    /// Interrupt pin not found
    InterruptPin,
}

const BASE_ADDRESS: u8 = 0x20;
const NUMBER_CHANNELS_SUPPORTED: u8 = 6;

#[derive(Clone, Copy, Debug)]
// TODO Change name to SourceSelector. Its not really a driver as domain info such as Source is used.
pub struct SourceSelectDriver<I2C: Write + WriteRead>
where
    I2C: WriteRead + Write,
{
    address_offset: u8,
    mcp23017_driver: MCP23017<I2C>,
}

impl<I2C, E> SourceSelectDriver<I2C>
where
    I2C: WriteRead<Error = E> + Write<Error = E>,
{
    pub fn new(i2c: I2C, address_offset: u8) -> Result<SourceSelectDriver<I2C>, Error> {
        let mut mcp23017_driver = mcp23017::MCP23017::new(i2c, BASE_ADDRESS + address_offset)
            .map_err(|_| Error::MCP23017(MCP23017Errors::Initialization))?;

        // The pins driving the leds are set to output mode and all but the
        // first one cleared.
        for i in 0..NUMBER_CHANNELS_SUPPORTED {
            mcp23017_driver
                .pin_mode(i, mcp23017::PinMode::OUTPUT)
                .map_err(|_| Error::MCP23017(MCP23017Errors::PinModeOutput(i)))?;

            if i == 0 {
                mcp23017_driver
                    .digital_write(i, true)
                    .map_err(|_| Error::ClearLED(i))?;
            } else {
                mcp23017_driver
                    .digital_write(i, false)
                    .map_err(|_| Error::ClearLED(i))?;
            }
        }

        Ok(SourceSelectDriver {
            address_offset,
            mcp23017_driver,
        })
    }

    /// Changes the source and also updates the source indicator.
    ///
    /// The changed source can be be retrived from `Sources` using the
    /// function `current_source()`.
    ///
    pub fn change_source(
        &mut self,
        //sources_iter: &'a mut SourceIterator,
        sources: &mut Sources,
    ) -> Result<(), Error> {
        // TODO try an remove the nested structure here
        defmt::info!("Changing source");
        if let Some(current_source) = sources.current_source() {
            let led_pin_number: u8 = current_source.display_position().into();
            // Clear the current source led
            self.mcp23017_driver
                .digital_write(led_pin_number, false)
                .map_err(|_| Error::ClearLED(led_pin_number))?;

            // Update the source
            if let Some(new_source) = sources.next() {
                let led_pin_number: u8 = new_source.display_position().into();
                // Now set the LED associated with the source
                self.mcp23017_driver
                    .digital_write(led_pin_number, true)
                    .map_err(|_| Error::SetLED)?;
                Ok(())
            } else {
                Ok(())
            }
        } else {
            Ok(())
        }
    }
}

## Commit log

2021-01-26 I2C connection to TAS5754 code compiles
2022-01-17 Version with 4051 multiplexers as routers
    [i2s-multiplexer.kicad_pcb, i2s-multiplexer.sch]
2022-01-17 Using buffers
    [i2s-multiplexer.kicad_pcb, i2s-multiplexer.sch]
2022-01-26 Initial PCB design
    [i2s-multiplexer.kicad_pcb, i2s-multiplexer.sch]
2022-01-26 Added test point
    [i2s-multiplexer.kicad_pcb, i2s-multiplexer.sch]
2022-01-27 Moved component together
    [i2s-multiplexer.kicad_pcb]
2022-01-27 Tuned i2s input tracks
    [i2s-multiplexer.kicad_pcb]
2022-01-27 Rationalised bus structure
    [i2s-multiplexer.kicad_pcb, i2s-multiplexer.sch]
2022-02-01 Minor routing changes
    [i2s-multiplexer.kicad_pcb, i2s-multiplexer.sch]
2022-02-02 Initial placement
    [i2s-multiplexer.kicad_pcb, i2s-multiplexer.sch]
2022-02-07 Input trace track length tuning
    [i2s-multiplexer.kicad_pcb, i2s-multiplexer.sch]
2022-02-15 Updated to KiCad 6
    [i2s-muliplexer-test.kicad_pcb, i2s-muliplexer-test.kicad_sch, i2s-multiplexer.kicad_pcb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]
2022-02-17 Test circuit can route i2s signals
    [i2s-muliplexer-test.kicad_sch]
2022-02-18 Added i2s multiplexer test code
    [i2s-muliplexer-test.kicad_sch]
2022-02-18 Rationalised directory structure
    [i2s-muliplexer.kicad_pcb, i2s-muliplexer.kicad_sch, i2s-muliplexer.sch]
2022-02-20 Layout with double row connectors
    [i2s-muliplexer.kicad_pcb, i2s-muliplexer.kicad_sch]
2022-02-20 Added symbols and adjusted silkscreen
    [i2s-muliplexer.kicad_pcb]
2022-02-20 Corrected mounting hole positions
    [i2s-muliplexer.kicad_pcb]
2022-02-20 Changed solder mask margins to 0 (default)
    [i2s-muliplexer.kicad_pcb]
2022-02-23 Initial ayout power board
    [power-board.kicad_pcb, power-board.kicad_sch]
2022-03-03 Created use case model
2022-03-09 Correct spelling directory name
    [i2s-muliplexer.kicad_pcb, i2s-muliplexer.kicad_sch, i2s-muliplexer.sch]
2022-03-10 Smaller board
    [power-board.kicad_pcb]
2022-03-10 Updated explanatory notes on schematic
    [power-board.kicad_sch]
2022-03-24 Adjusted width of select buttons
2022-03-28 Select buttons have a radio button function
2022-04-04 Restructured use case diagrams
2022-04-05 Select buttons now flash
2022-04-11 Refactored source and select button ids
2022-04-20 Demo of timer (as BT connect simulation) works
2022-08-16 Schematic with 3.5 inch display and Pico board
    [controller.kicad_pcb, controller.kicad_sch]
2022-12-03 Removed 3.5 inch display from schematic
    [controller.kicad_sch]
2022-12-03 Revised powerchain (diode, new symbol)
    [controller.kicad_sch]
2022-12-07 Added sense signal
    [controller.kicad_sch]
2023-02-15 Controller schematic and PCB design
    [controller.kicad_pcb, controller.kicad_sch]
2023-02-22 Initial sketch of the select-button-board
    [select-buttons-board.kicad_pcb, select-buttons-board.kicad_sch]
2023-02-22 Initial schematic of select-button-board
    [select-buttons-board.kicad_sch]
2023-02-23 Simplified directory structure
    [select-buttons-board.kicad_pcb, select-buttons-board.kicad_sch]
2023-03-04 Added (temp) backlight control
    [controller.kicad_sch]
2023-03-08 Corrections as of now
    [controller.kicad_sch, select-buttons-board.kicad_sch]
2023-03-21 Updated and new pictures of circuts/boards etc.
2023-03-21 New schematic for the system wiring
    [wiring-loom.kicad_pcb, wiring-loom.kicad_sch]
2023-03-21 KiCad version changes
2023-03-21 Corrections to schematics. WARNING PCB out of date
    [controller.kicad_sch]
2023-03-23 New KiCad version
2023-03-23 Initial design of source display processor
    [source-display-processor.kicad_pcb, source-display-processor.kicad_sch]
2023-04-03 Changed name of the interrupt to SOURCE_CHANGED
    [source-display-processor.kicad_sch]
2023-04-06 Added functions to i2c-multiplexer
2023-04-06 Added corrections regarding the i2s-multiplexer interface
    [controller.kicad_sch]
2023-04-06 Removed experimental termination as it is not required
    [controller.kicad_sch]
2023-04-11 Added the I2SMultiplexer driver lib
2023-04-11 source-select-driver is now a module
2023-04-22 Current state before trying a new source structure
2023-05-04 Current unfinished state
2023-05-08 Added activate_initial_source task - does not now crash
    [main.rs, source_select_driver.rs]
2023-05-08 Added annotation
    [controller.kicad_sch]
2023-05-08 KIcad changed this
2023-07-02 Small changes to controller circuit
    [controller.kicad_sch]
2023-09-13 Keep up to date with actual circuit
    [controller.kicad_sch]
2023-10-14 Compiles - with known errors - but test does not work
    [main.rs, source_select_driver.rs]
2023-10-16 Noted that simpler NOT to use interrupt pins
    [source-display-processor.kicad_sch]
2023-10-17 CHANGE_SOURCE directly driven from push button
    [source-display-processor.kicad_sch]
2023-10-17 Removed MCP23017 interrupt configuration code
2023-10-19 Corrected interrupt bug
2023-10-20 Can coordinate multiple devices
2023-10-21 GPIO currently used for UART1 documented
    [controller.kicad_sch]
2023-11-07 Added no connection symbol
    [source-display-processor.kicad_sch]
2023-11-07 Added RC reset circuit
    [source-display-processor.kicad_sch]
